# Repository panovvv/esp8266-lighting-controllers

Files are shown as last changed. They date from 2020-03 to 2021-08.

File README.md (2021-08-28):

# ESP8266 Lighting controllers

diyHue-compatible smart lighting controllers from inexpensive easy-to-source components.

* ESP-12 RGBCCT (5 channels) controller

    * Prototype
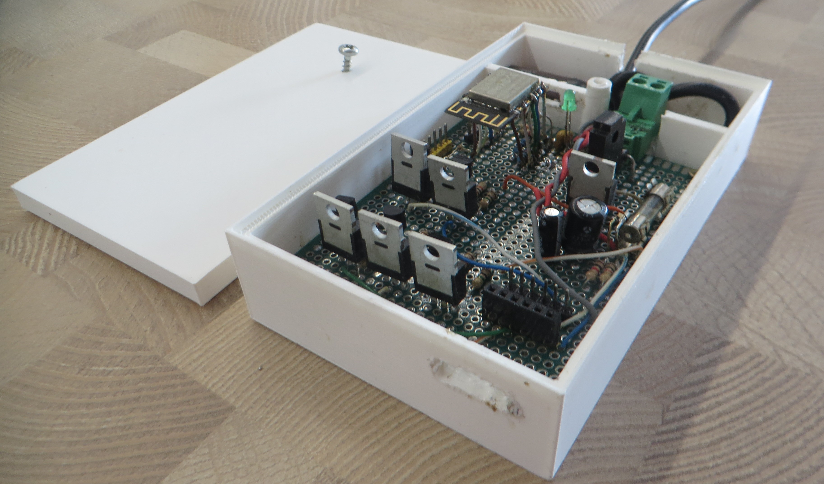
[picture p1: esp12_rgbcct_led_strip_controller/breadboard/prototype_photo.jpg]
      
    * PCB render
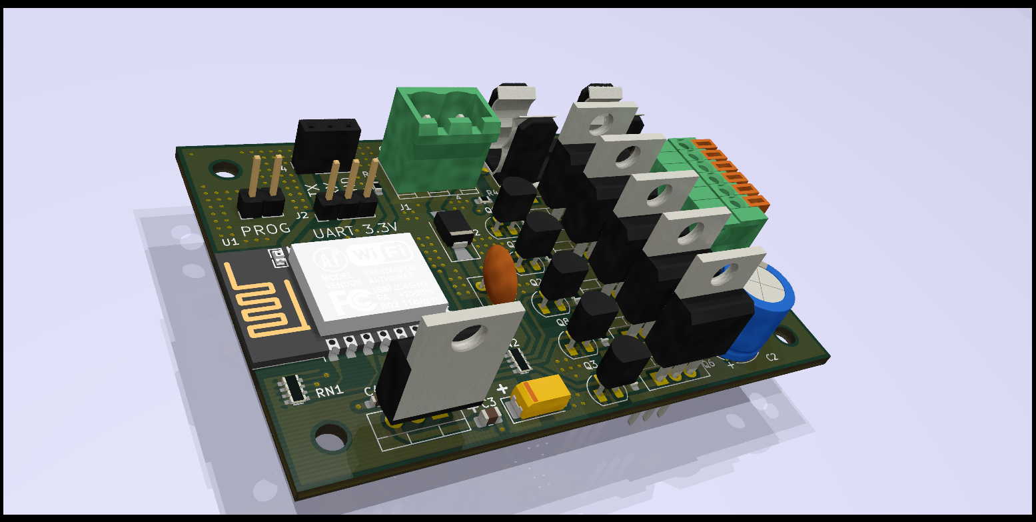
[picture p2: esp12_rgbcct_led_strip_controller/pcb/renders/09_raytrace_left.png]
      
    * PCB
      
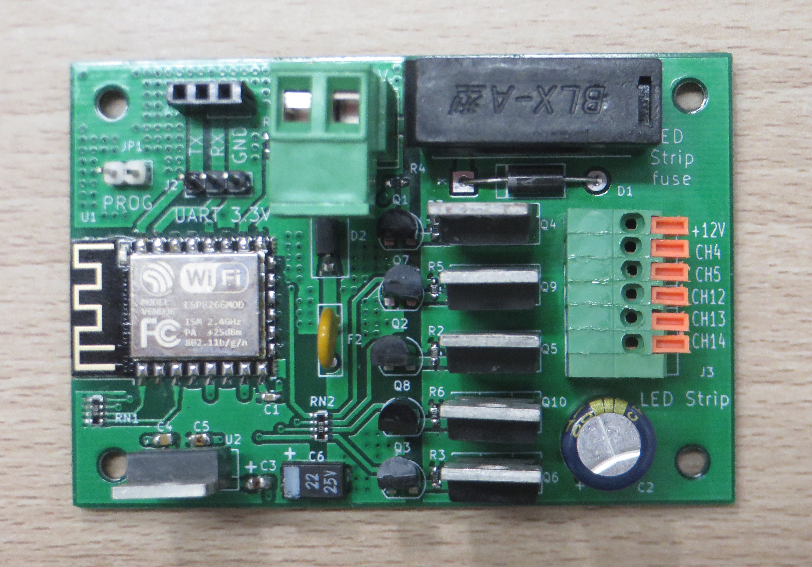
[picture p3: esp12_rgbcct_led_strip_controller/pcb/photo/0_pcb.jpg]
      
    * Regular enclosure
      
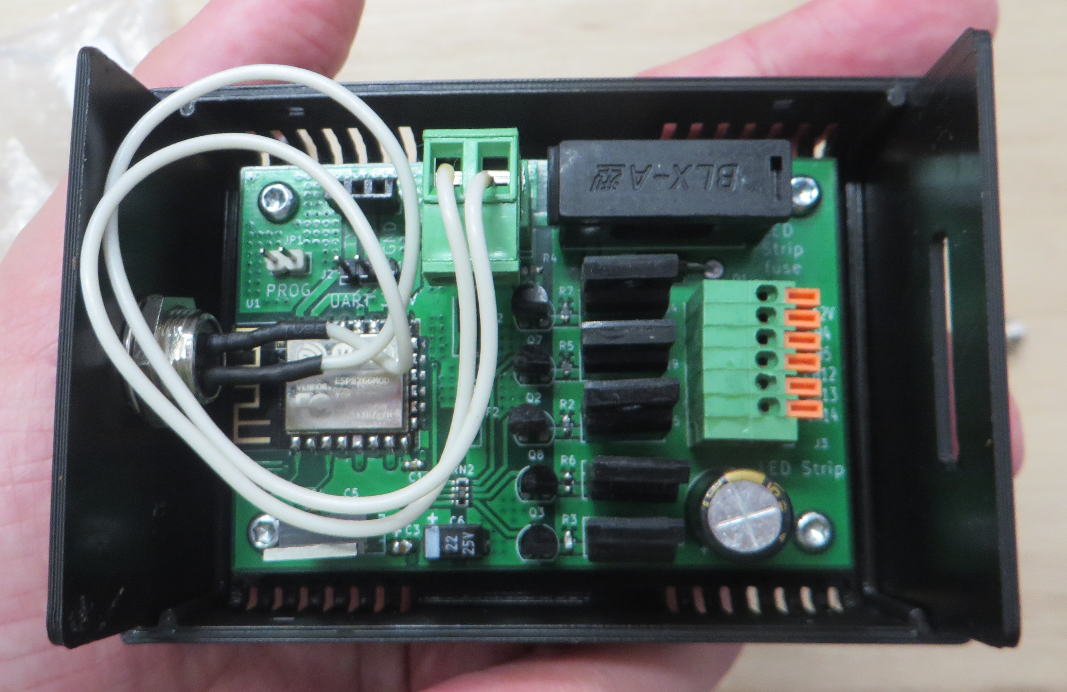
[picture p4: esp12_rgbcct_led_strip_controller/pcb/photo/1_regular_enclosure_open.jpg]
      
      
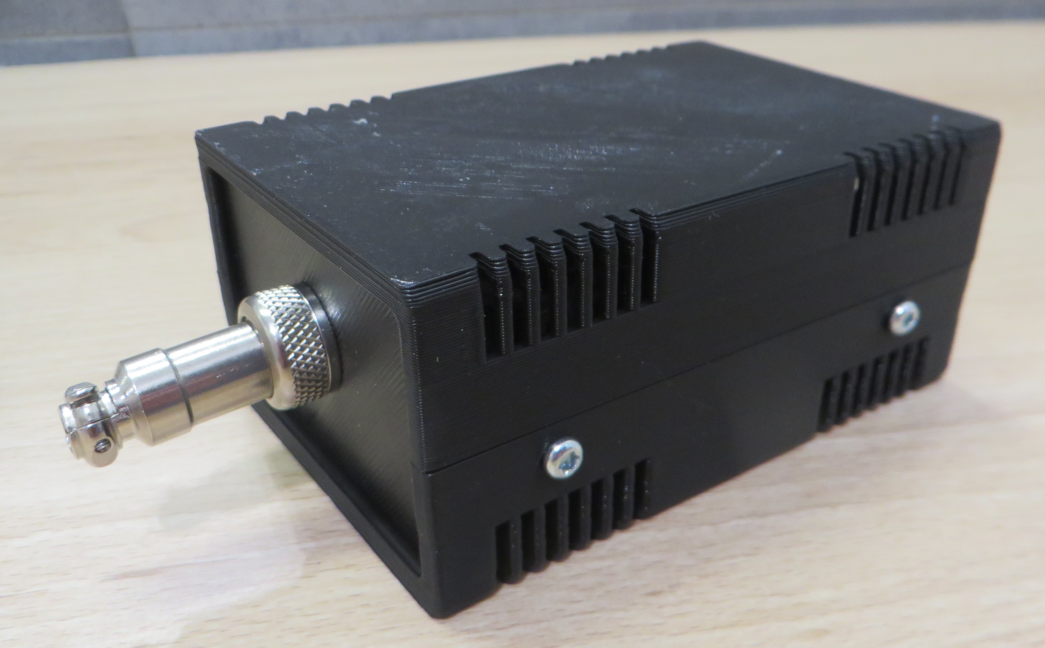
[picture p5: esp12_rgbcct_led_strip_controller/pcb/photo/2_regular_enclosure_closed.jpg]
      
      
    * Waterproof enclosure
      
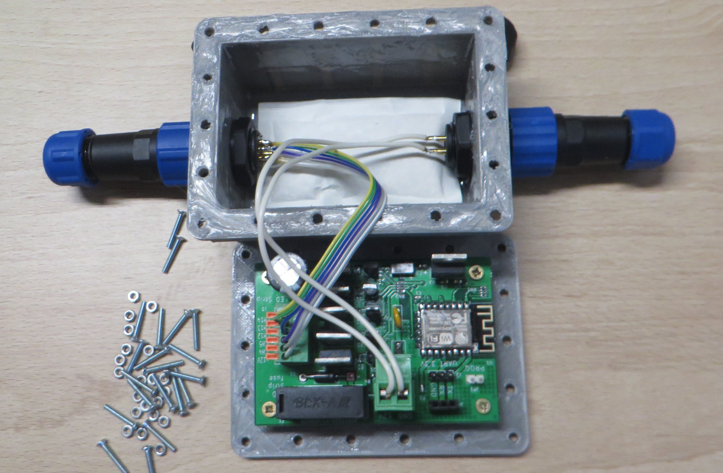
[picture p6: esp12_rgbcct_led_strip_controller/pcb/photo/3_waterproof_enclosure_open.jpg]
      
      
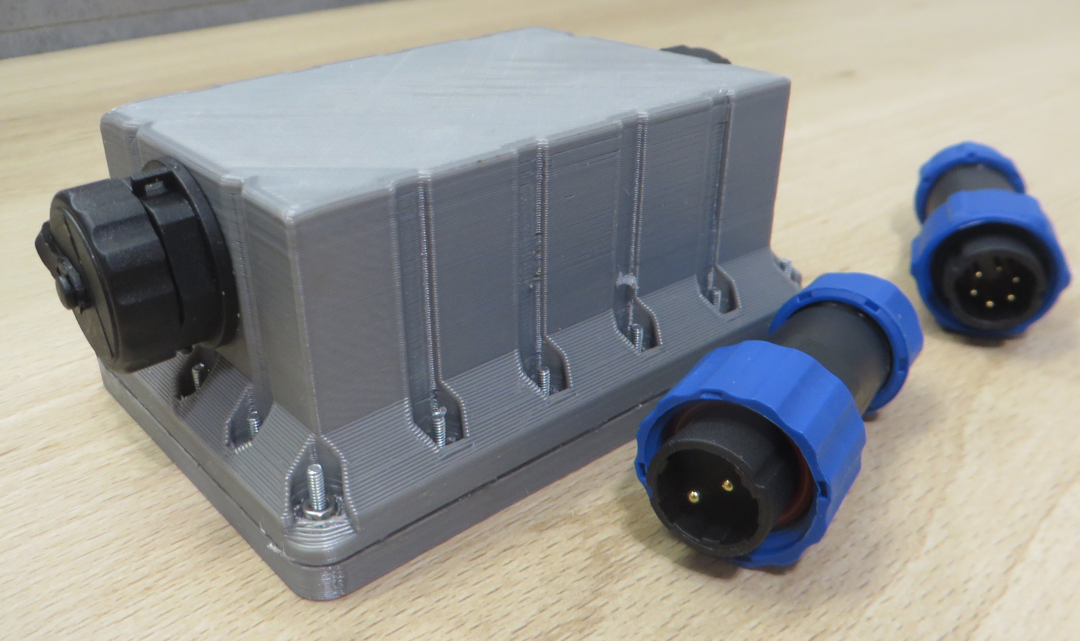
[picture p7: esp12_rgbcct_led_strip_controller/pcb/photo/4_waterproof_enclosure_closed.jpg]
      

* ESP-01 Neopixel (WS2812) controller

    * Schematic
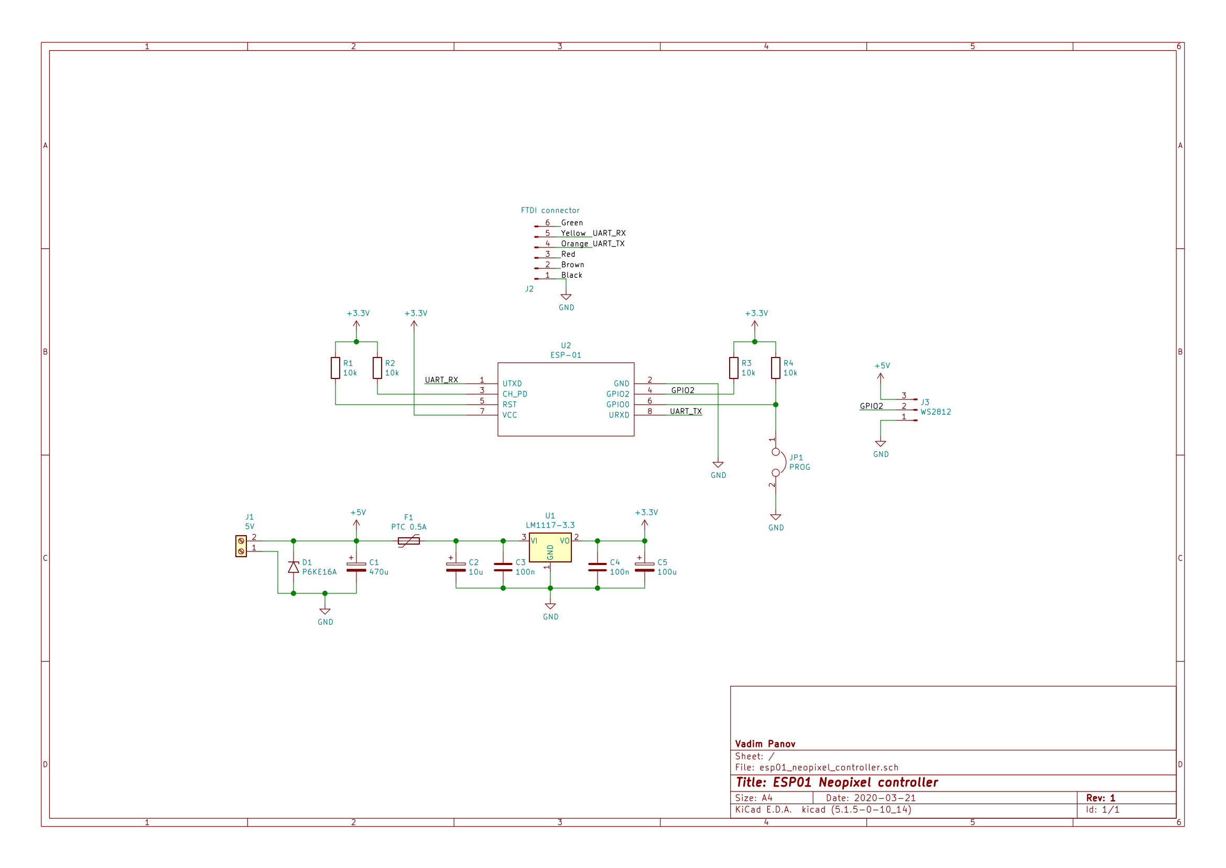
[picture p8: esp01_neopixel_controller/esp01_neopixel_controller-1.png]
      
    * Prototype
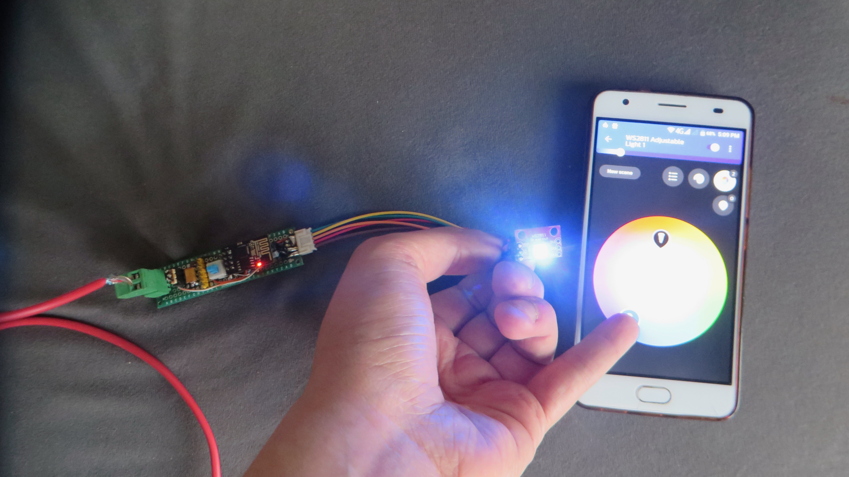
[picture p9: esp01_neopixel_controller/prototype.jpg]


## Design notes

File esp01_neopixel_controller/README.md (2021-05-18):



This schematic uses the ESP-01 symbol from this library:

https://github.com/jdunmire/kicad-ESP8266

Clone this library and point KiCAD to ESP8266.lib 
if you want to customize this schematic.

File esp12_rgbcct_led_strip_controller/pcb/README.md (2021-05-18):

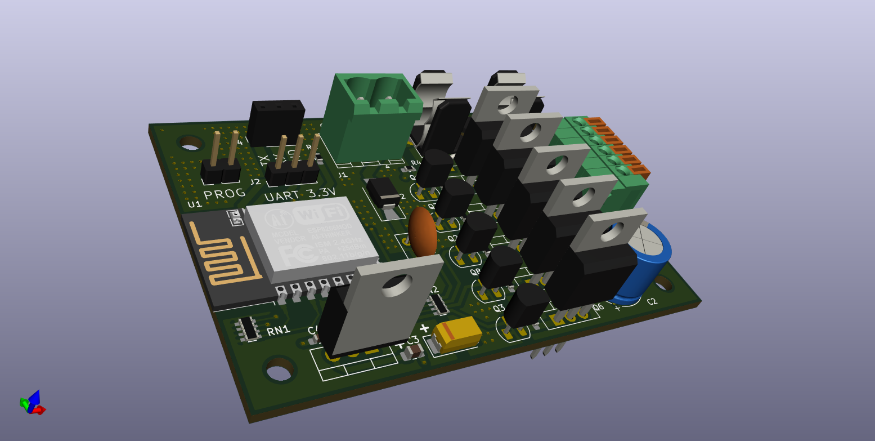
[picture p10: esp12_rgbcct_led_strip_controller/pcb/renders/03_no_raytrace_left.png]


# Files and folders:

* `esp-12_led_strip_controller.***, fp-lib-table` - KiCAD schematics and PCB files.
* `schematic.pdf` - full schematic sheet rendered in PDF.
* `bom.csv` - Bill of Materials, Tab-separated.
* `paper_footprint_test.pdf` - this is my usual practice when designing and ordering PCBs:
before even designing the board layout, I plot the empty board with all footprints in it to PDF
(1:1 scale), print it on a sheet of paper and do a "test fit" for every component. This helps 
to find footprint inconsistencies early on.
* `enclosure/` - OpenSCAD script + STL files. [Source](https://github.com/jbebel/Ultimate-Box-Maker)
* `enclosure_waterproof/` - waterproof enclosure (think bathrooms), designed in FreeCAD 0.18 . 
* `gerber/` - Generated according to
[this document](https://support.jlcpcb.com/article/102-kicad-515---generating-gerber-and-drill-files).
To order the PCB made, just zip up all files in `gerber/` folder and send to fab.
* `renders/` - 3D renders and STL of the board with all components populated.

# Dependencies

* _KF141V-6P_P2.54mm_ footprint from [Connector_KEFA_Homemade](https://github.com/panovvv/homemade-kicad-libraries) 

# BOM

| Designator | Package | Quantity | Designation |
|---|---|---|---|
| R1 - R7 | 0603 (1608 metric) | 7 | 10k resistor. |
| U2 | TO-220 3 pin | 1 | LM1117-3.3 voltage regulator (3.3V) |
| C1, C4, C5 | 0603 (1608 metric) | 3 | 100n capacitor. |
| J3 | KF141V-6P, 2.54mm spacing | 1 | LED Strip connector – spring cage type. |
| C2 | Radial polarized capacitor, D=10.0mm, P=5.00mm/7.50mm | 1 | 1000u capacitor. |
| C3 | 0805 (2012 metric) | 1 | 10u capacitor. |
| C6 | EIA-6032-28 / Kemet-C, pad size: 2.25x2.35mm | 1 | 100u tantalum capacitor (or any other capacitor that fits the footprint) |
| D1 | DO-15 | 1 | P6KE16A - TVS diode 16V. |
| D2 | SMA or SMB (Universal) | 1 | Any surface mount diode in SMA or SMB package. |
| F1 | Cylindric fuse holder - 5x20mm | 1 | LED strip fuse holder. Fuse current = total current consumption of your strip + some headroom. |
| F2 | Disc capacitor, D=8.0mm, W=2.5mm, P=5.00mm | 1 | PTC fuse, 0.5A. |
| Q1, Q2, Q3, Q7, Q8  | TO-92 | 5 | NPN transistor, EBC(123) configuration (e,g, 2N2222) |
| Q4, Q5, Q6, Q9, Q10 | TO-220 3 pin. | 5 | N type MOSFET, GDS(123) configuration (e,g, IRF3205) |
| RN1, RN2 | Resistor array, convex, 4x0603 | 2 | 10k resistor network. |
| U1 | ESP-12 | 1 | ESP-12E or ESP-12F. |
| J1 | PhoenixContact MSTBVA 2,5 2-G-5,08, 1x02, 5.08mm spacing. | 1 | 12V input. Can be replaced with any similar connector. |
| JP1 | Pin header, 1x02, 2.54mm spacing. | 1 | PROG jumper. |
| J2 | Pin header, 1x03, 2.54mm spacing. | 1 | UART male connector. |
| J4 | Pin socket, 1x02, 2.54mm spacing. | 1 | UART female connector. |

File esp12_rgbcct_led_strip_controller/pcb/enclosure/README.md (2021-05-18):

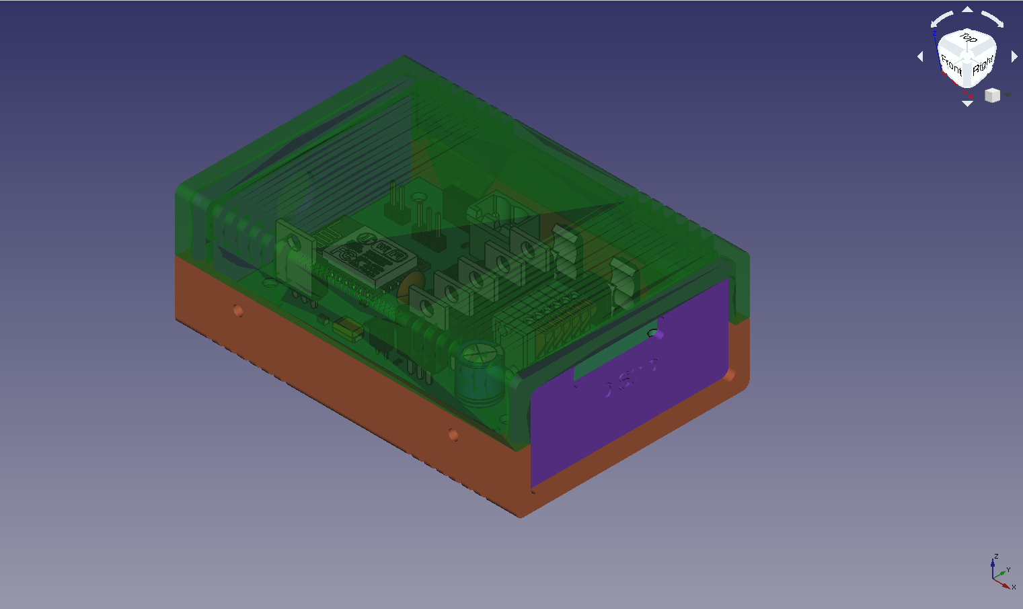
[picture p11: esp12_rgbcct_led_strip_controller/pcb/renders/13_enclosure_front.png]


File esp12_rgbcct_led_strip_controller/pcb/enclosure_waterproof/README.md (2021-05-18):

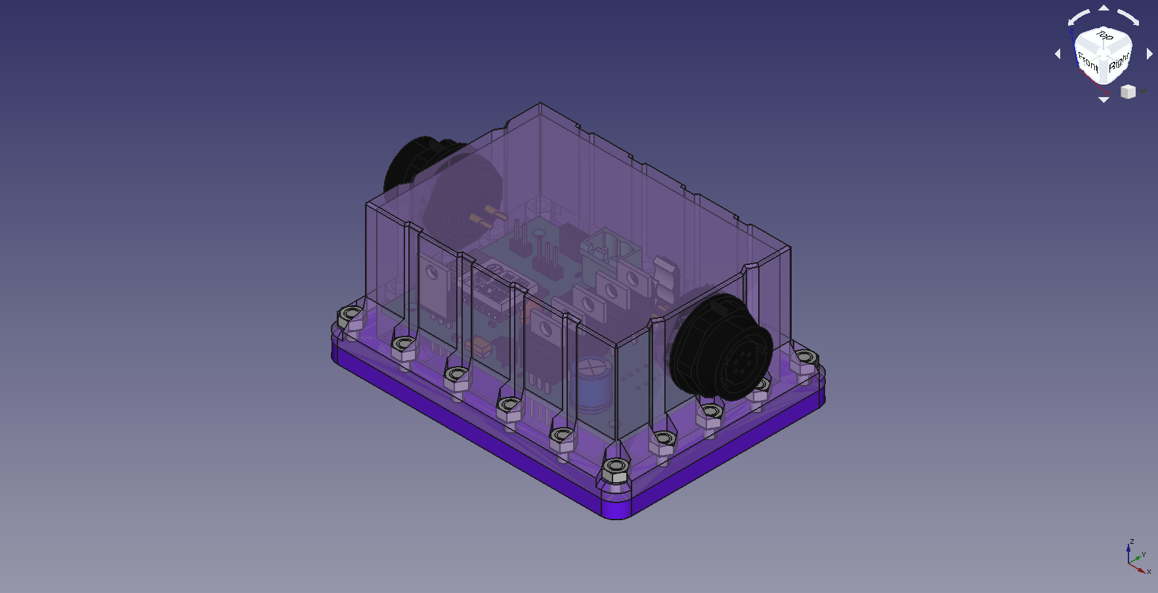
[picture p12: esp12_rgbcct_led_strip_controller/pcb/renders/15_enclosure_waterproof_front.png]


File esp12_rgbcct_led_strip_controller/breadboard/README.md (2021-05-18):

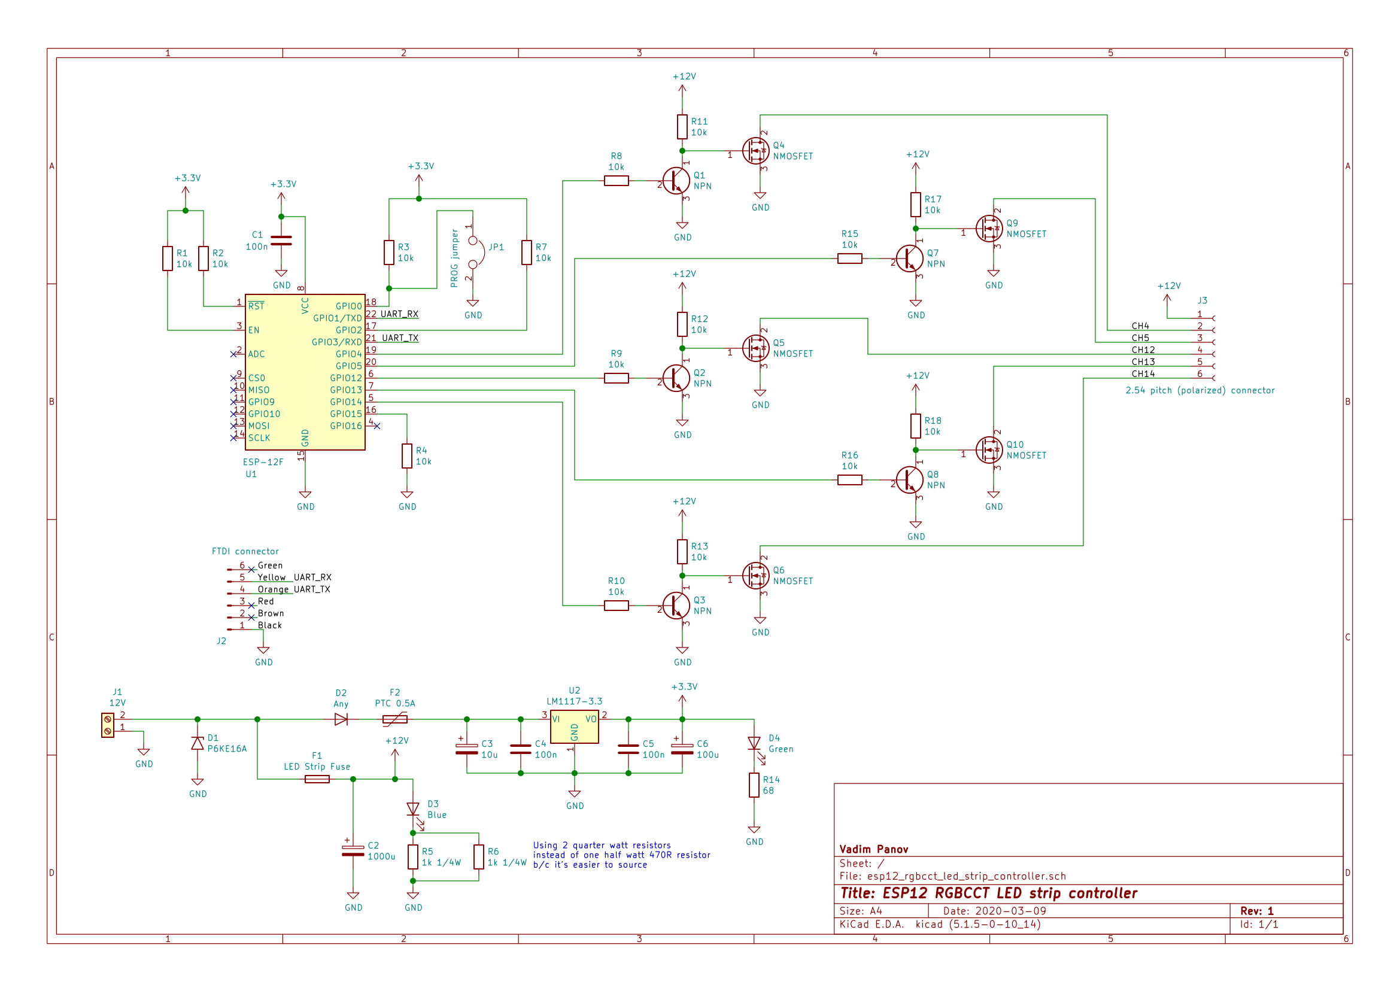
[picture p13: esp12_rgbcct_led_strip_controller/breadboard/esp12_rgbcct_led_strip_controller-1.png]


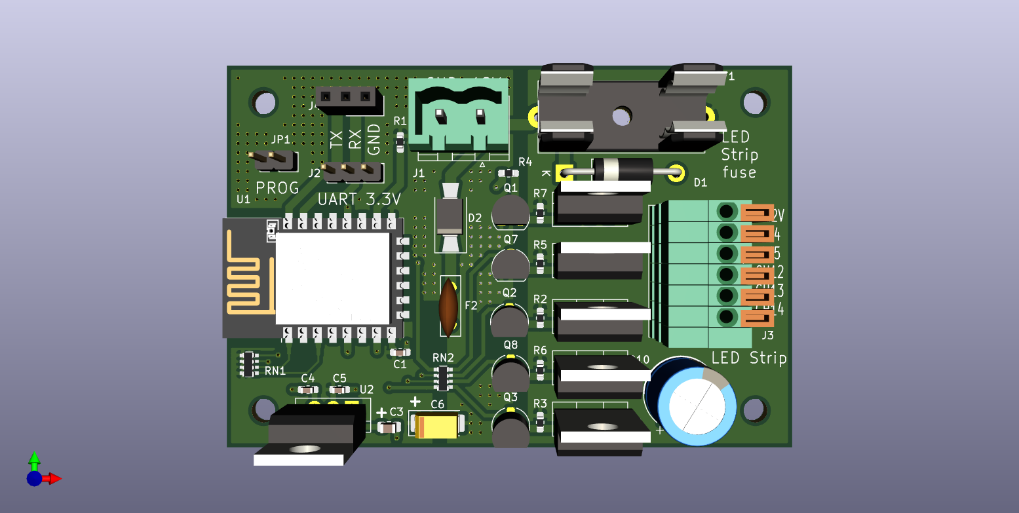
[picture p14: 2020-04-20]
esp12_rgbcct_led_strip_controller/pcb/renders/01_no_raytrace_front.png

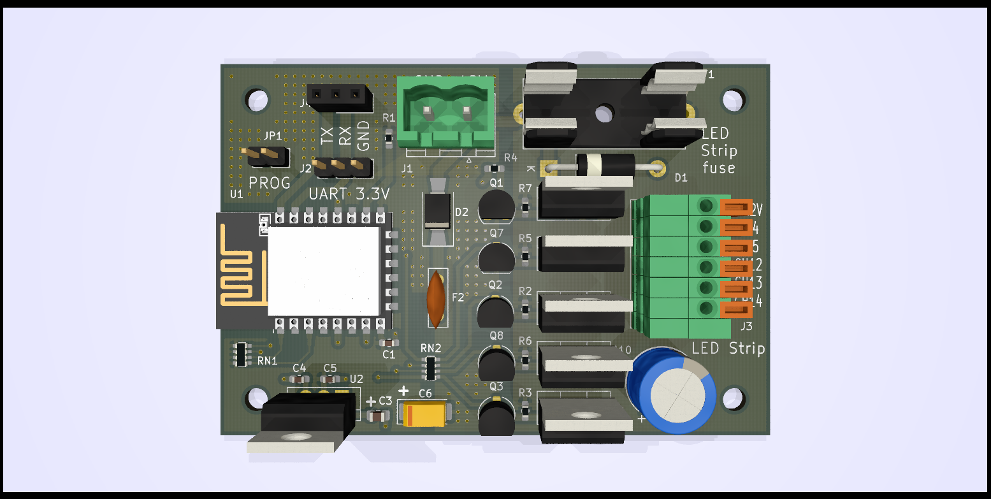
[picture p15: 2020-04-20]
esp12_rgbcct_led_strip_controller/pcb/renders/07_raytrace_front.png

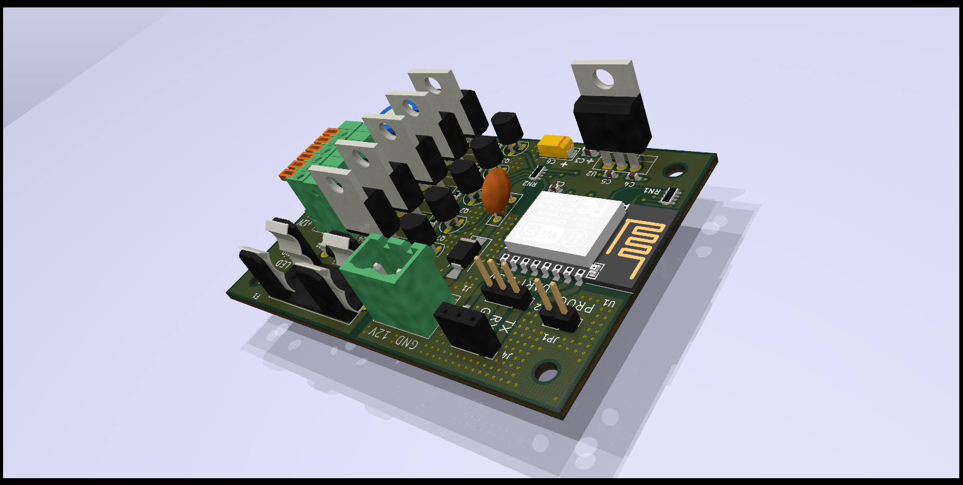
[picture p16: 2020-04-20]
esp12_rgbcct_led_strip_controller/pcb/renders/11_raytrace_left_180deg.png

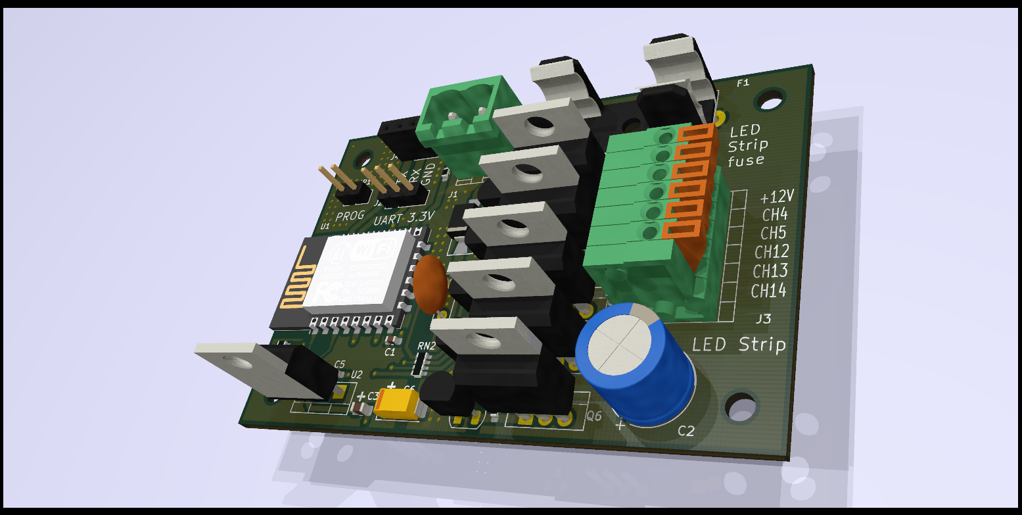
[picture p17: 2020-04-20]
esp12_rgbcct_led_strip_controller/pcb/renders/10_raytrace_right.png

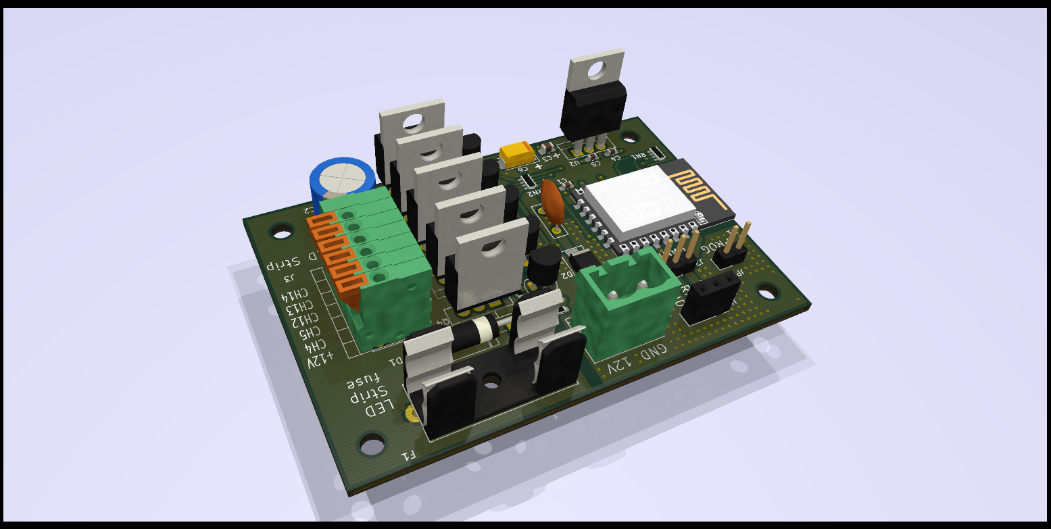
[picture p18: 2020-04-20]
esp12_rgbcct_led_strip_controller/pcb/renders/12_raytrace_right_180deg.png

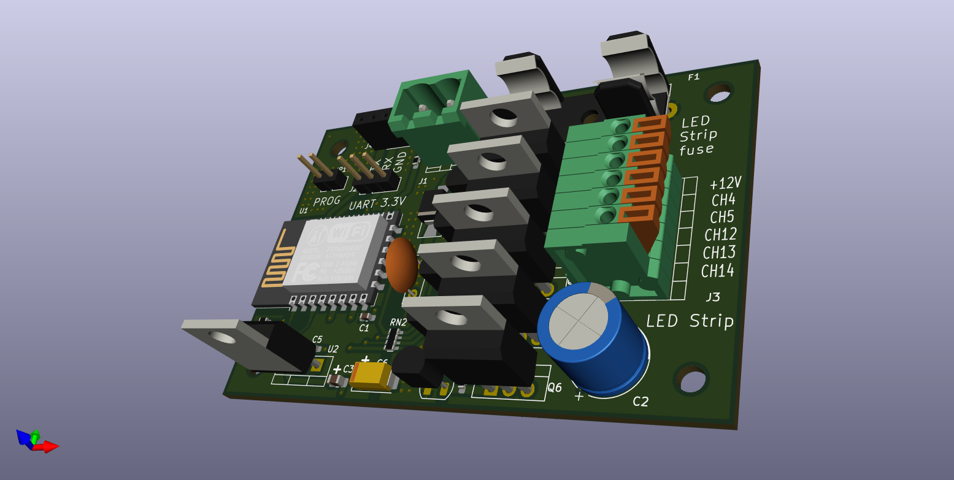
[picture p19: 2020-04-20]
esp12_rgbcct_led_strip_controller/pcb/renders/04_no_raytrace_right.png

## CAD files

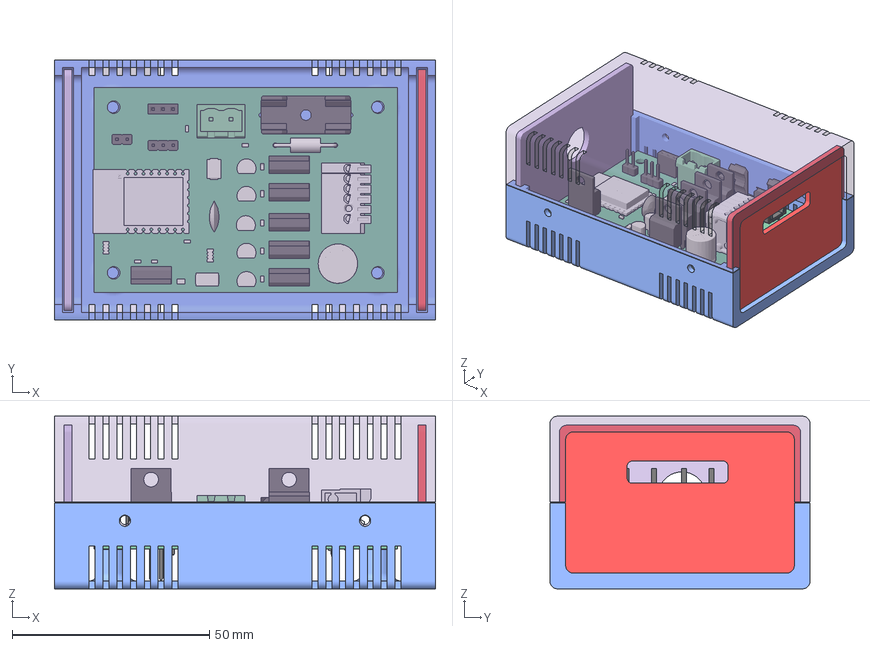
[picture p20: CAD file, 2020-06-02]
esp12_rgbcct_led_strip_controller/pcb/enclosure/full_assembly.FCStd
96.6 x 66.0 x 43.8 mm
Pcb_5b54
R6_R_0603_1608Metric_5E9C2952
R5_R_0603_1608Metric_5E9C2A8A
R3_R_0603_1608Metric_5E9C2982
R2_R_0603_1608Metric_5E9C29B2
U2_TO-220-3_Vertical_5E9B5751
C5_C_0603_1608Metric_5E9B5718
C4_C_0603_1608Metric_5E9B56E5
J3_KF141V-6P_P2.54mm_5E9C2657
C1_C_0603_1608Metric_5E91E38A
C2_CP_Radial_D100mm_P500mm_P750mm_5E9CC6F6
C3_C_0805_2012Metric_5E91E46E
C6_CP_EIA_6032_28_Kemet_C_5E9C8505
D1_D_DO-15_P15.24mm_Horizontal_5E9B9CF2
D2_D_SMB_5E9B6E28
F1_A_Schurter_0031_8201_5E9C40DC
F2_C_Disc_D80mm_W25mm_P500mm_5E9CBA76
Q1_TO-92_Narrow_5E9C2AEB
Q2_TO-92_Narrow_5E9C2B1E
Q3_TO-92_Narrow_5E9C0DBD
Q4_TO-220-3_Vertical_5E9C0E43
Q5_TO-220-3_Vertical_5E9C0CE1
Q6_TO-220-3_Vertical_5E9B9F12
Q7_TO-92_Narrow_5E9C2A58
Q8_TO-92_Narrow_5E9C2A25
Q9_TO-220-3_Vertical_5E9C0E8E
Q10_TO-220-3_Vertical_5E9C0B8E
R1_R_0603_1608Metric_5E92F775
R7_R_0603_1608Metric_5E9C2B50
RN1_R_Array_Convex_4x0603_5E9C9216
RN2_R_Array_Convex_4x0603_5E9C29E8
U1_ESP-12-E-better_5E9C08FA
J1_MSTBVA_01x02_G_5_08mm_5E9B6F19
JP1_PinHeader_1x02_P254mm_Vertical_5E9244EE
R4_R_0603_1608Metric_5E9C2ABA
J2_PinHeader_1x03_P254mm_Vertical_5E94568C
J4_PinSocket_1x03_P254mm_Vertical_5E945586
bottom
top
back
front

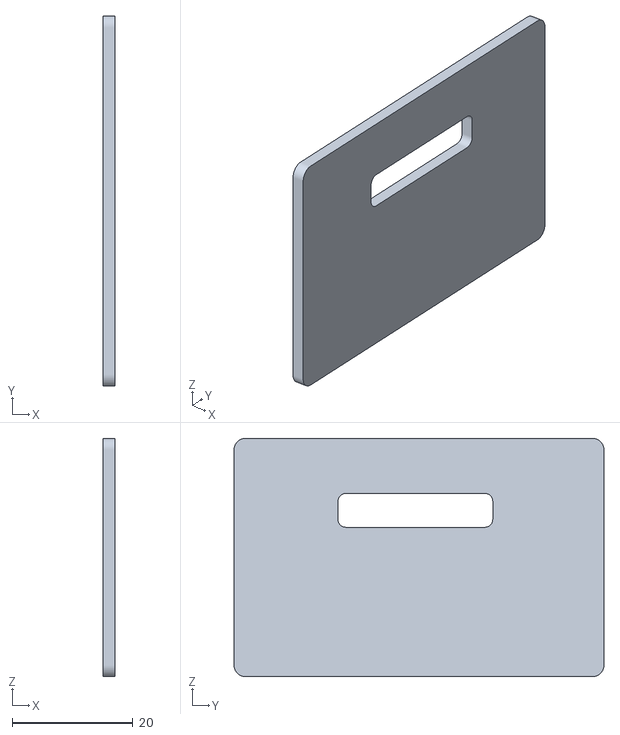
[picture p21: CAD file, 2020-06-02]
esp12_rgbcct_led_strip_controller/pcb/enclosure/front.stl
2.00 x 61.2 x 39.4

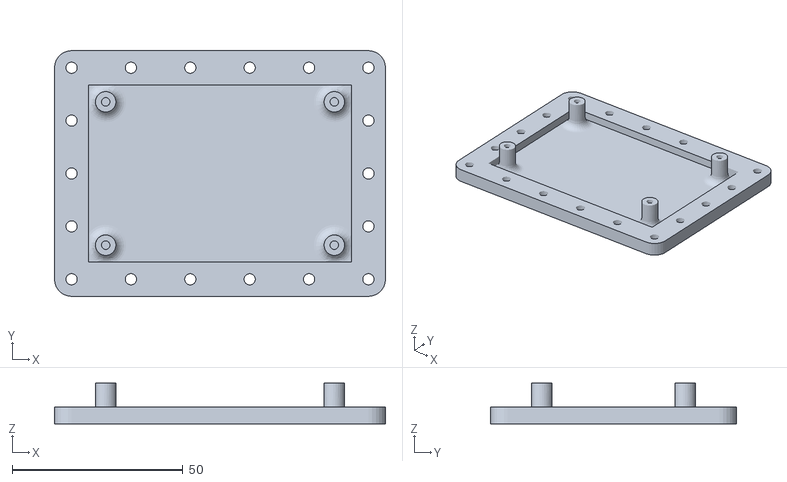
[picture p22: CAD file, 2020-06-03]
esp12_rgbcct_led_strip_controller/pcb/enclosure_waterproof/enclosure_bottom.stl
97.0 x 72.0 x 12.0

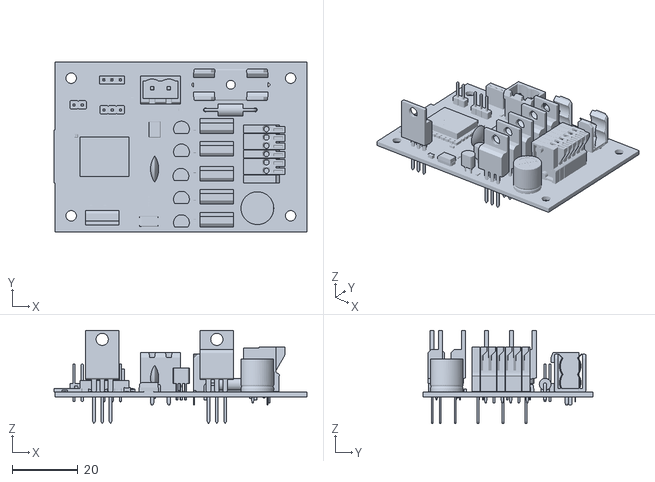
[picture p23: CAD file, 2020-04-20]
esp12_rgbcct_led_strip_controller/pcb/renders/esp-12_led_strip_controller.stl
77.2 x 52.0 x 28.5

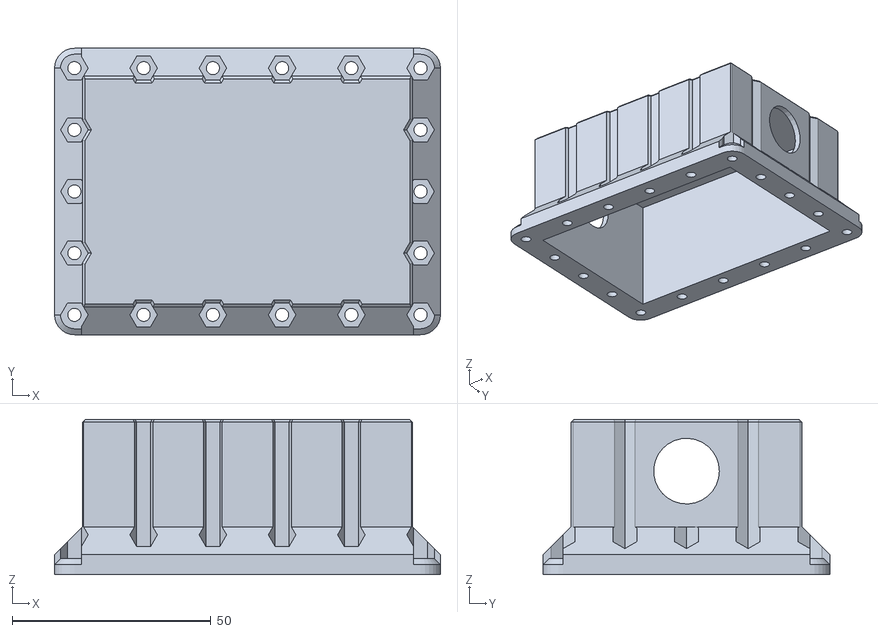
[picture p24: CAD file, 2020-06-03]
esp12_rgbcct_led_strip_controller/pcb/enclosure_waterproof/enclosure_top.stl
97.0 x 72.0 x 39.0

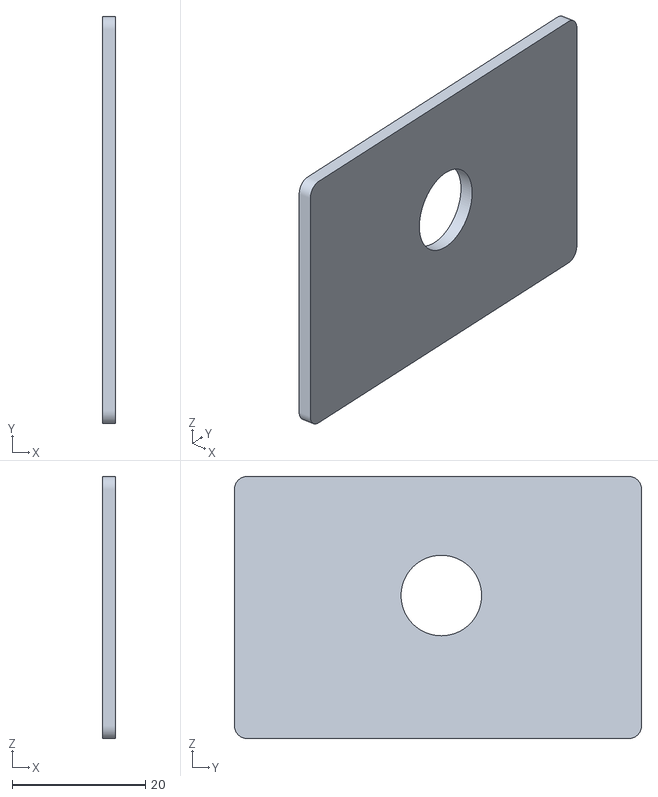
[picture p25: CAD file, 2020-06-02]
esp12_rgbcct_led_strip_controller/pcb/enclosure/back.stl
2.00 x 61.2 x 39.4

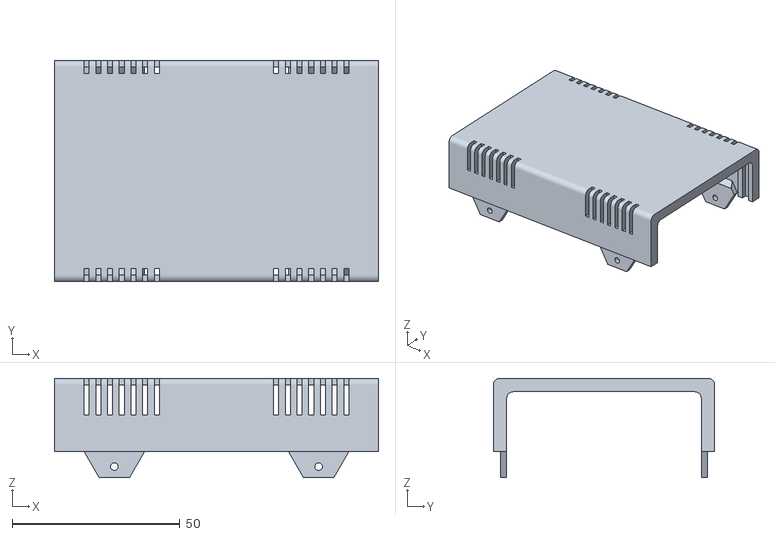
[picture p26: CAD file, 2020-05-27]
esp12_rgbcct_led_strip_controller/pcb/enclosure/top.stl
96.6 x 66.0 x 29.6

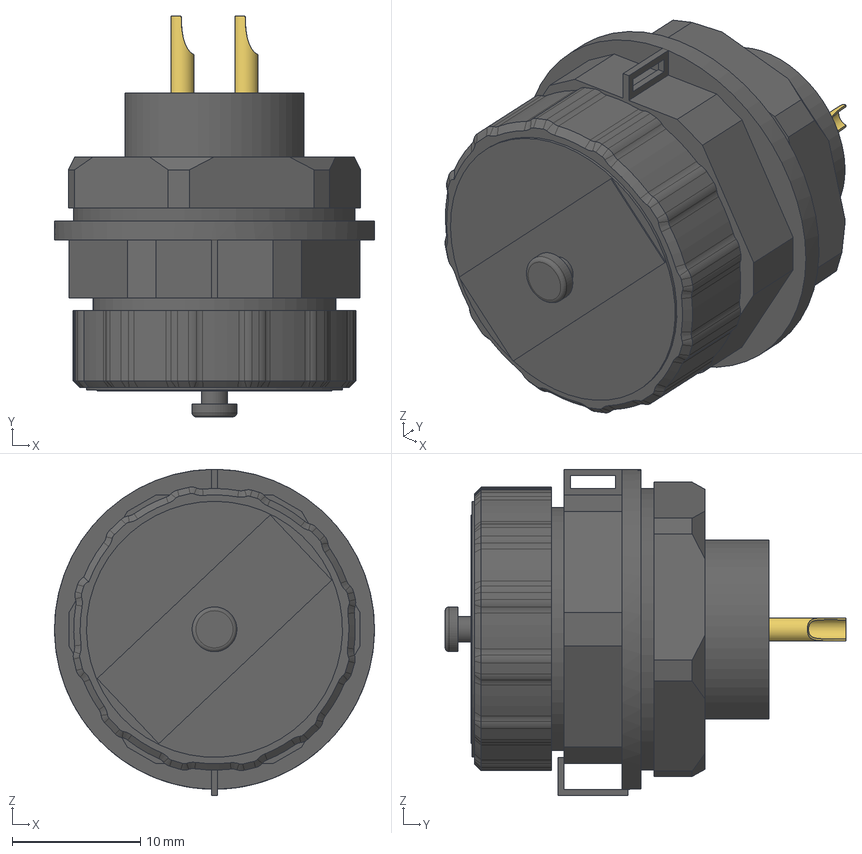
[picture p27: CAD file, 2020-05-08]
esp12_rgbcct_led_strip_controller/pcb/enclosure_waterproof/SP16-2P, female, back nut type, with cap.stp
25.0 x 31.3 x 25.5 mm
cap
rubber_washer
nut
nut_1
center_2p_female_body
pin x 2

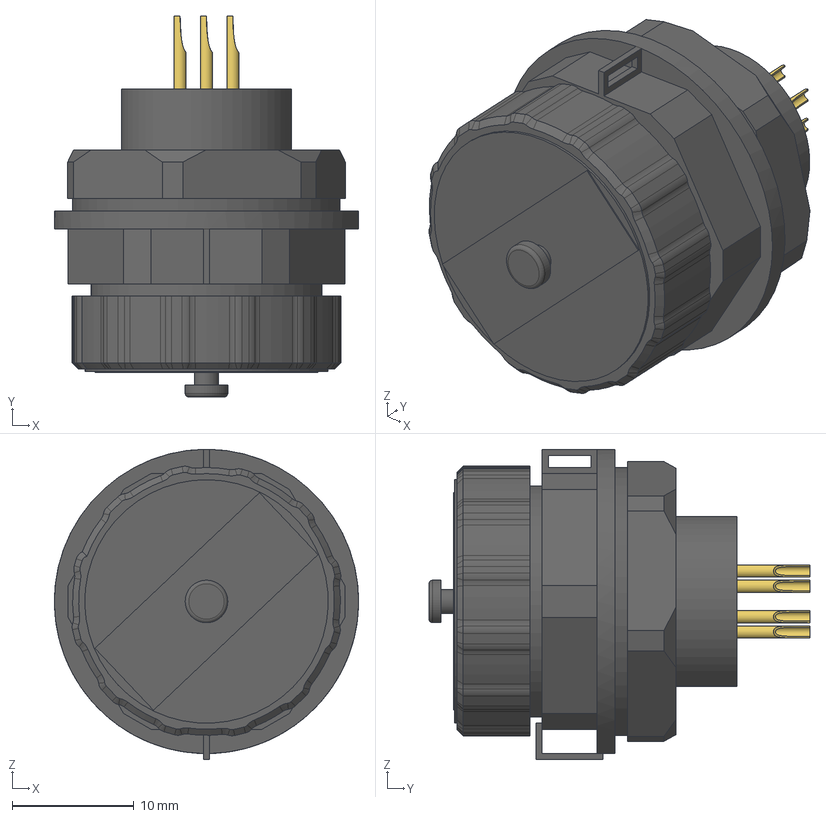
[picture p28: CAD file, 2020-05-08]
esp12_rgbcct_led_strip_controller/pcb/enclosure_waterproof/SP16-6P, female, back nut type, with cap.stp
25.0 x 31.3 x 25.5 mm
cap
rubber_washer
nut
nut_1
center_2p_female_body
pin x 6

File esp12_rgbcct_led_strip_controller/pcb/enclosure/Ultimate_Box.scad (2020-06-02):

/* Box design originally by:
////////////////////////////////////////////////////////////////////
              -    FB Aka Heartman/Hearty 2016     -
              -   http://heartygfx.blogspot.com    -
              -       OpenScad Parametric Box      -
              -         CC BY-NC 3.0 License       -
////////////////////////////////////////////////////////////////////

Improved by jbebel:
http://github.com/jbebel/Ultimate-Box-Maker

To create a box, start by modifying the numerical parameters in the sections
below. This can be accomplished using a release of OpenSCAD newer than 2015.03.
As of the time of writing, this means that a development snapshot is required.
The Thingiverse Customizer may also potentially work, but at the time of
writing, it was inoperable.

The simplest choice is to hand-edit the .scad file. Feature toggles are
annotated with a comment. The other numerical parameters are measurements in
mm. Everything is parametrized, so if you double all the non-feature parameters
you will double the box size in every dimension. Certain parameters are derived
from other parameters. If you wish to override them, you may, but sensible
defaults have been chosen. Notably the design in this revision is particularly
PCB-centric, in that you should start with your PCB size and adjust the margins
around it to determine the box size. If you care more about the box size, you
can set the Length, Width, and Height explicitly, but read the comments around
them.

Once your box is sized appropriately, you can use the Panel modules to design
the holes and text for the front and back panels. Helper variables are provided
to assist you in positioning these holes relative to the PCB, if your holes are
for PCB-mounted components.

When you are ready to print, adjust the values in the "STL element to export"
section, and export each part one at a time.

Experimental options are provided for a screwless design, but these are
untested. In particular, the box fixation tabs may need thicknesses adjusted
in order to have the appropriate flexibility.
*/

// preview[view:north east, tilt:top diagonal]
//----------------------- Box parameters ---------------------------

/* [Box options] */
// - Wall thickness
Thick = 2;
// - Panel thickness
PanelThick = 2;
// - Font Thickness
FontThick = 0.5;
// - Filet Radius
Filet = 2;
// - 0 for beveled, 1 for rounded
Round = 1; // [0:No, 1:Yes]
// - Printer margin around interior cutouts
CutoutMargin = 0.3;
// - Margin between mating parts
PartMargin = 0.1;
// - PCB feet? (x4)
PCBFeet = 1; // [0:No, 1:Yes]
// - Decorations?
Decorations = 1; // [0:No, 1:Yes]
// - Decorations to ventilation holes
Vent = 1; // [0:No, 1:Yes]
// - Decoration-Holes width (in mm)
Vent_width = 1.5;
// - Tolerance (Panel/rails gap on one edge)
PanelThickGap = CutoutMargin + PartMargin;
PanelVerticalGap = PartMargin;
PanelHorizontalGap = CutoutMargin + PartMargin;


/* [Box Fixation Tabs] */
// - Side screw hole (or snap) diameter
ScrewHole = 2.2606;
// - Screw thread major diameter for outer shell
BoxHole = 2.8448;
// Thickness of fixation tabs
TabThick = 2;
// Back left tab
BLTab = 1; // [0:Bottom, 1:Top]
// Back right tab
BRTab = 1; // [0:Bottom, 1:Top]
// Front left tab
FLTab = 1; // [0:Bottom, 1:Top]
// Front right tab
FRTab = 1; // [0:Bottom, 1:Top]
// EXPERIMENTAL: Snap tabs
SnapTabs = 0; // [0:Screws, 1:Snaps]


/* [PCB options] */
// - PCB Length
PCBLength = 80;
// - PCB Width
PCBWidth = 144;
// - PCB Thickness
PCBThick = 1.6;
// You likely need to maintain |TabThick| margin on the left and right for tabs
// and whatnot.
// - Margin between front panel and PCB
FrontEdgeMargin = 70;
// - Margin between back panel and PCB
BackEdgeMargin = 0;
// - Margin between left wall and PCB
LeftEdgeMargin = 11;
// - Margin between right wall and PCB
RightEdgeMargin = 11;
// - Margin between top of PCB and box top.
TopMargin = 84;


/* [PCB_Feet] */
// - Foot height above box interior
FootHeight = 8;
// - Foot diameter
FootDia = 8;
// - Hole diameter, or peg for screwless design
FootHole = 2.2606; // tap size for #4 coarse-thread
// - EXPERIMENTAL Screwless design
Screwless = 0; // [0:Screws, 1:Screwless]
FootFilet = FootHeight/4;

// Foot centers are specified as distance from PCB back-left corner.
// X is along the "length" axis, and Y is along the "width" axis.
// - Foot 1 distance from back PCB edge
Foot1X = 5;
// - Foot 1 distance from left PCB edge
Foot1Y = 5;
// - Foot 2 distance from back PCB edge
Foot2X = 5;
// - Foot 2 distance from right PCB edge
Foot2YFromEdge = 5;
Foot2Y = PCBWidth - Foot2YFromEdge;
// - Foot 3 distance from front PCB edge
Foot3XFromEdge = 5;
Foot3X = PCBLength - Foot3XFromEdge;
// - Foot 3 distance from left PCB edge
Foot3Y = 5;
// - Foot 4 distance from front PCB edge
Foot4XFromEdge = 5;
Foot4X = PCBLength - Foot4XFromEdge;
// - Foot 4 distance from right PCB edge
Foot4YFromEdge = 5;
Foot4Y = PCBWidth - Foot4YFromEdge;


/* [STL element to export] */
// - Top shell
TShell = 0; // [0:No, 1:Yes]
// - Bottom shell
BShell = 1; // [0:No, 1:Yes]
// - Front panel
FPanL = 1; // [0:No, 1:Yes]
// - Back panel
BPanL = 1; // [0:No, 1:Yes]
// - Panel holes and text
PanelFeatures = 0; // [0:No, 1:Yes]


/* [Hidden] */
// - Shell color
Couleur1 = "Orange";
// - Panel color
Couleur2 = "OrangeRed";
// - Text color
TextColor = "White";
// - making decorations thicker if it is a vent to make sure they go through
// shell
// Add a small number to Thick in case Filet is 0.
Dec_Thick = Vent ? Thick*1.001 + Filet : Thick/2;
// Separate vents with a square pillar by default.
Dec_Spacing = Thick + Vent_width;
// X offset to center of first vent
Dec_Offset = Thick*2 + PanelThick + PanelThickGap*2 + Dec_Spacing - Vent_width/2;

// Resolution based on Round parameter. Set this first number to something
// smaller to speed up processing. It should always be a multiple of 4.
Resolution = Round ? 100: 4;

/* Calculate box dimensions from PCB. If you want a more box-centric design
   where the outer diameter of the box matters more than the margins around
   the PCB you can set these manually. The PCB will still be placedaccording
   to the left and back margins, and if you want to use the screwless box
   design, you will need to set the TopMargin to
   (Height - Thick*2 - FootHeight - PCBThick)
*/
Length = PCBLength + FrontEdgeMargin + BackEdgeMargin + ((Thick + PanelThick + PanelThickGap*2)*2);
Width = PCBWidth + LeftEdgeMargin + RightEdgeMargin + Thick*2;
Height = FootHeight + PCBThick + TopMargin + Thick*2;
echo("Box: ", Length=Length, Width=Width, Height=Height);
// X position inset of mounting holes and tabs
MountInset = Thick*3 + PanelThick + PanelThickGap*2 + ScrewHole*4;

// Calculate panel dimensions from box dimensions.
PanelWidth = Width - Thick*2 - PanelHorizontalGap*2;
PanelHeight = Height - Thick*2 - PanelVerticalGap*2;


/*  Panel Manager

    Use the below 4 modules to produce holes and text on the front and back
    panels. The holes modules should contain instances of SquareHole or
    CylinderHole defined later in this file. The text modules should contain
    instances of LText or CText defined later in this file. It is
    recommended to use variables that you define for your needs to create
    the size and positions of these objects.
*/

// Calculate board-relative positions with respect to the panel, for
// convenience in placing panel elements.
TopOfBoardWRTPanel = FootHeight + PCBThick - PanelVerticalGap;
LeftEdgeOfBoardWRTFPanel = LeftEdgeMargin - PanelHorizontalGap;
LeftEdgeOfBoardWRTBPanel = RightEdgeMargin - PanelHorizontalGap;
// Visible panel edges
PanelBottomEdge = Thick - PanelVerticalGap;
PanelTopEdge = PanelHeight - Thick + PanelVerticalGap;
PanelLeftEdge = Thick - PanelHorizontalGap;
PanelRightEdge = PanelWidth - Thick + PanelHorizontalGap;


// Holes for front panel
module FPanelHoles() {
    // SquareHole(On/Off, Xpos,Ypos,Length,Width,Filet)
    SquareHole(1, (PanelRightEdge-PanelLeftEdge)/2-11.5, 25, 25, 5, 1);
    // SquareHole(1, 40, 20, 15, 10, 1);
    // SquareHole(1, 60, 20, 15, 10, 1);
    // CylinderHole(On/Off, Xpos, Ypos, Diameter)
    // CylinderHole(1, 27, 40, 8);
    // CylinderHole(1, 47, 40, 8);
    // CylinderHole(1, 67, 40, 8);
    // SquareHole(1, 20, 50, 80, 30, 3);
    // CylinderHole(1, 93, 30, 10);
    // SquareHole(1, 120, 20, 30, 60, 3);
}


// Text for front panel
module FPanelText() {
    // LText(On/Off, Xpos, Ypos, "Font", Size, "Text", "HAlign", "VAlign")
    //LText(1, (PanelRightEdge-PanelLeftEdge)/2-12.5, 13, "Arial Black", 4, "LED Strip", HAlign="left");
    // LText(1, 120, 83, "Arial Black", 4, "Level", HAlign="left");
    // LText(1, 20, 11, "Arial Black", 6, "  1     2      3", HAlign="left");
    // CText(On/Off, Xpos, Ypos, "Font", Size, Diameter, Arc(Deg), Starting Angle(Deg),"Text")
    // CText(1, 93, 29, "Arial Black", 4, 10, 180, 0,
    //      ["1", "." , "3", "." , "5", "." , "7", "." , "9", "." , "11"]);
}
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

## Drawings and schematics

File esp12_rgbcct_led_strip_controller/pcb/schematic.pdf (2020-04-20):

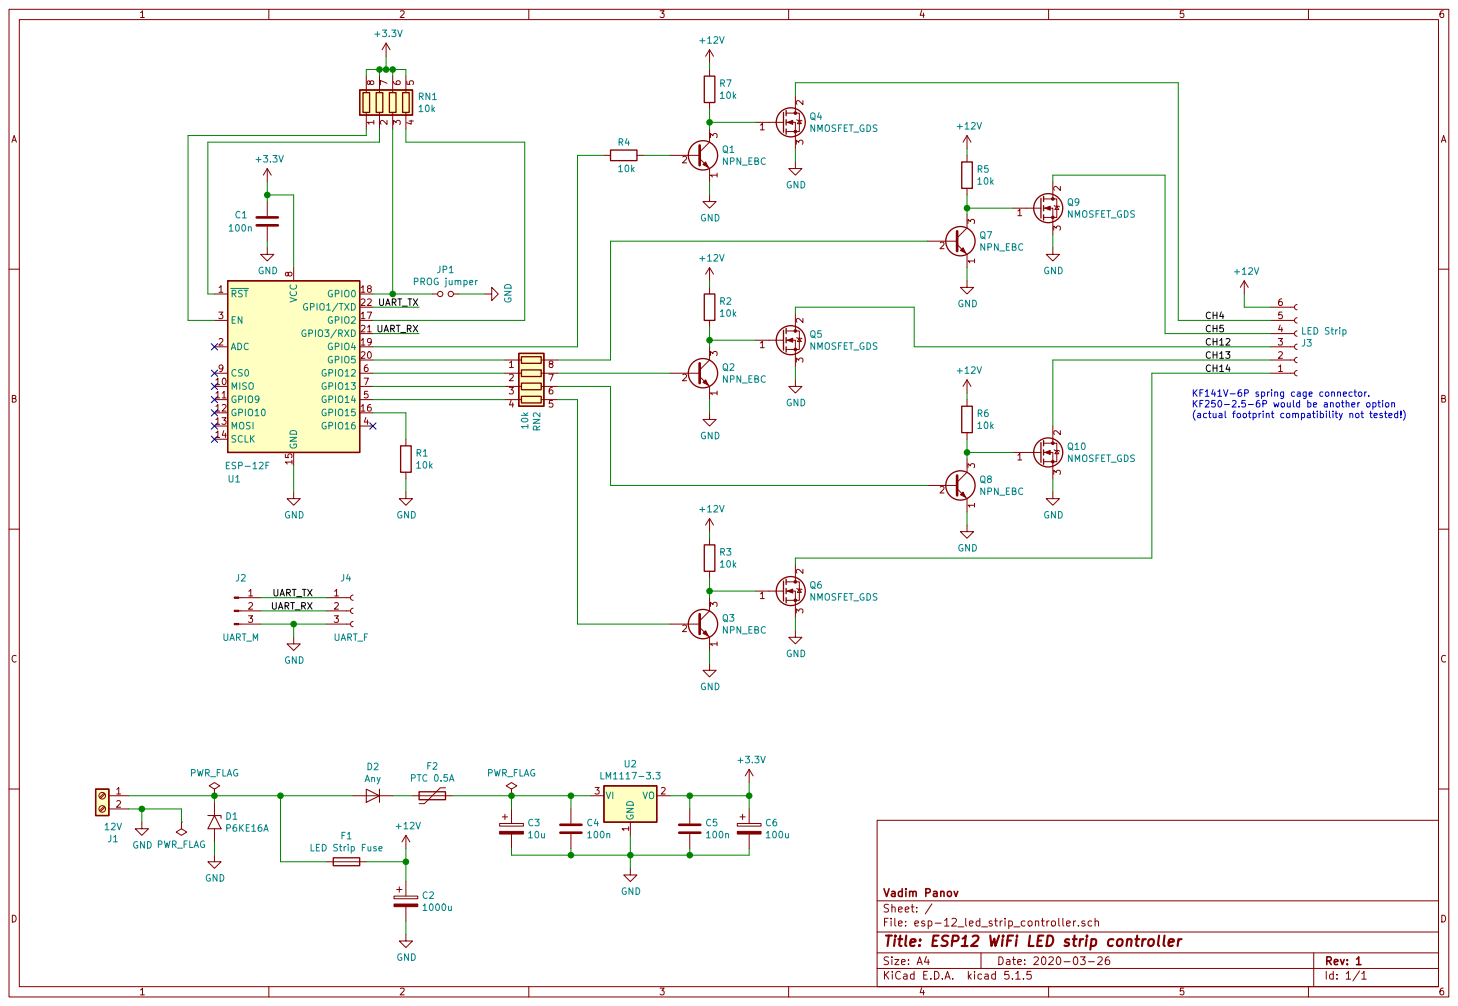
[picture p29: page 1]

KF250-2.5-6P would be another option
(actual footprint compatibility not tested!)

File: esp-12_led_strip_controller.sch Sheet: / Vadim Panov

Id: 1/1 Title: ESP12 WiFi LED strip controller

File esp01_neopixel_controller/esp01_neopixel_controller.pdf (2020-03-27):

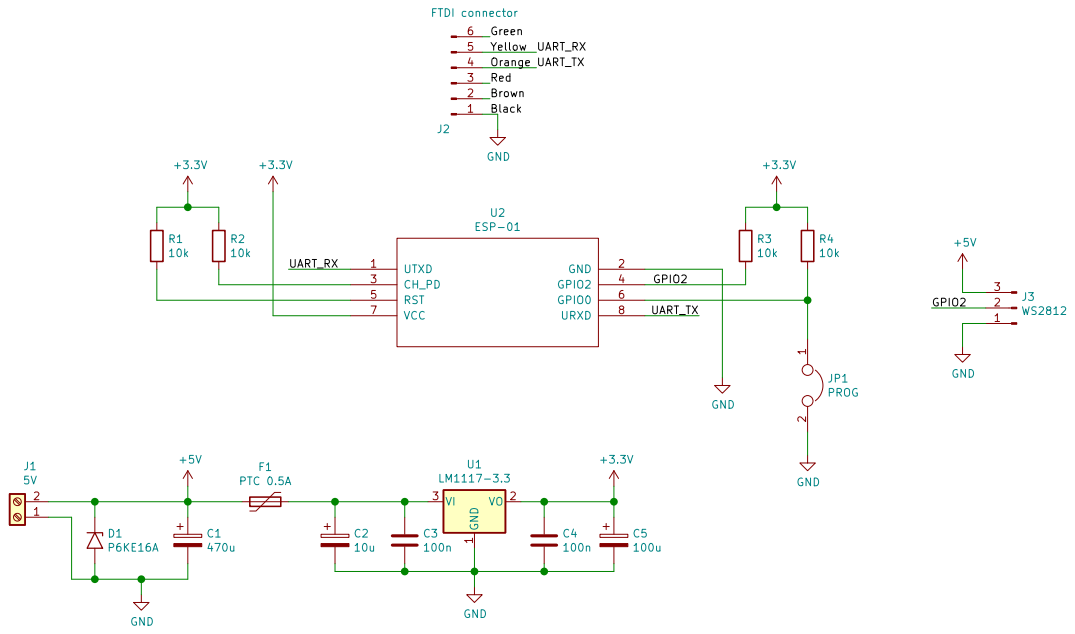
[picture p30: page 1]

File: esp01_neopixel_controller.sch Sheet: / Vadim Panov GND

Id: 1/1 Title: ESP01 Neopixel controller

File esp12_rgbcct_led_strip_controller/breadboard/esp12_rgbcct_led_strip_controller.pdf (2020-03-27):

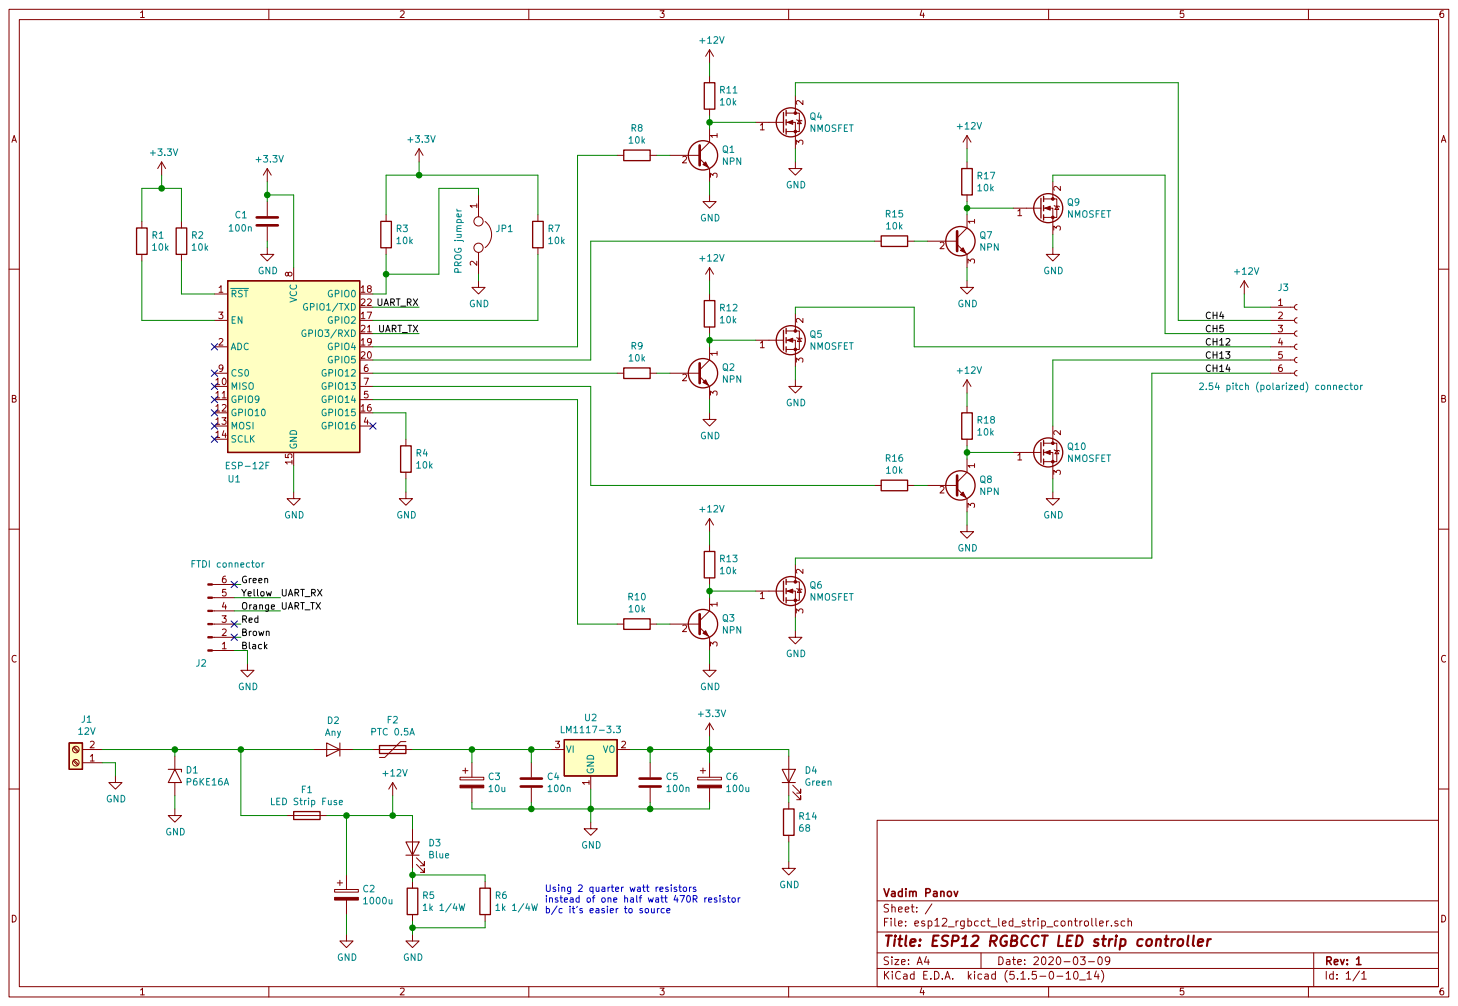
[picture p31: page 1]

File: esp12_rgbcct_led_strip_controller.sch Sheet: / Vadim Panov

instead of one half watt 470R resistor b/c its easier to source

Id: 1/1 Title: ESP12 RGBCCT LED strip controller

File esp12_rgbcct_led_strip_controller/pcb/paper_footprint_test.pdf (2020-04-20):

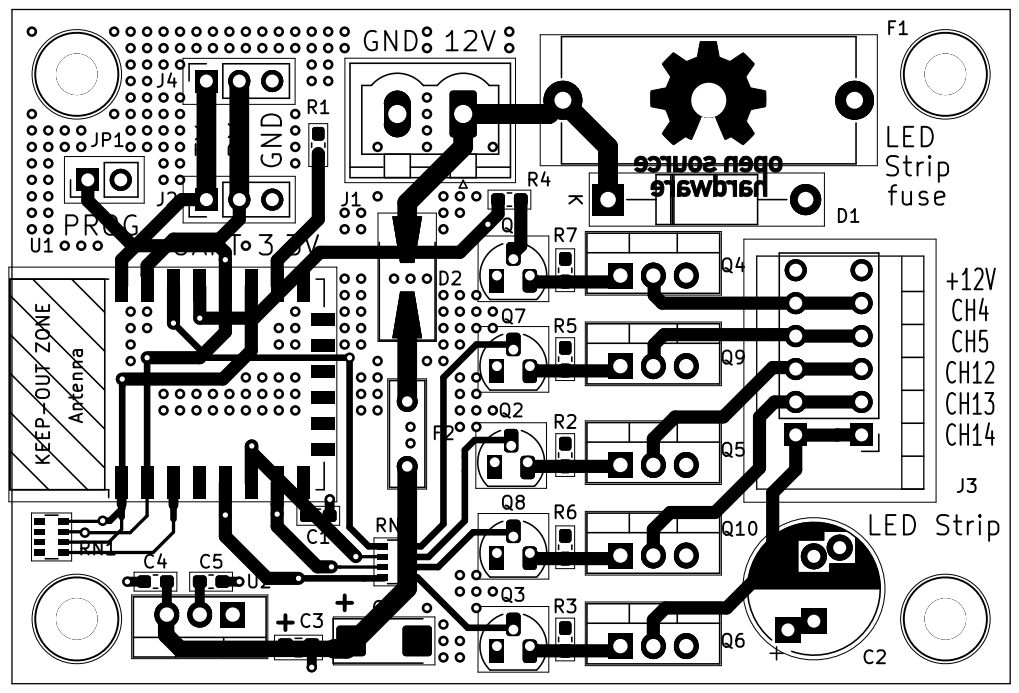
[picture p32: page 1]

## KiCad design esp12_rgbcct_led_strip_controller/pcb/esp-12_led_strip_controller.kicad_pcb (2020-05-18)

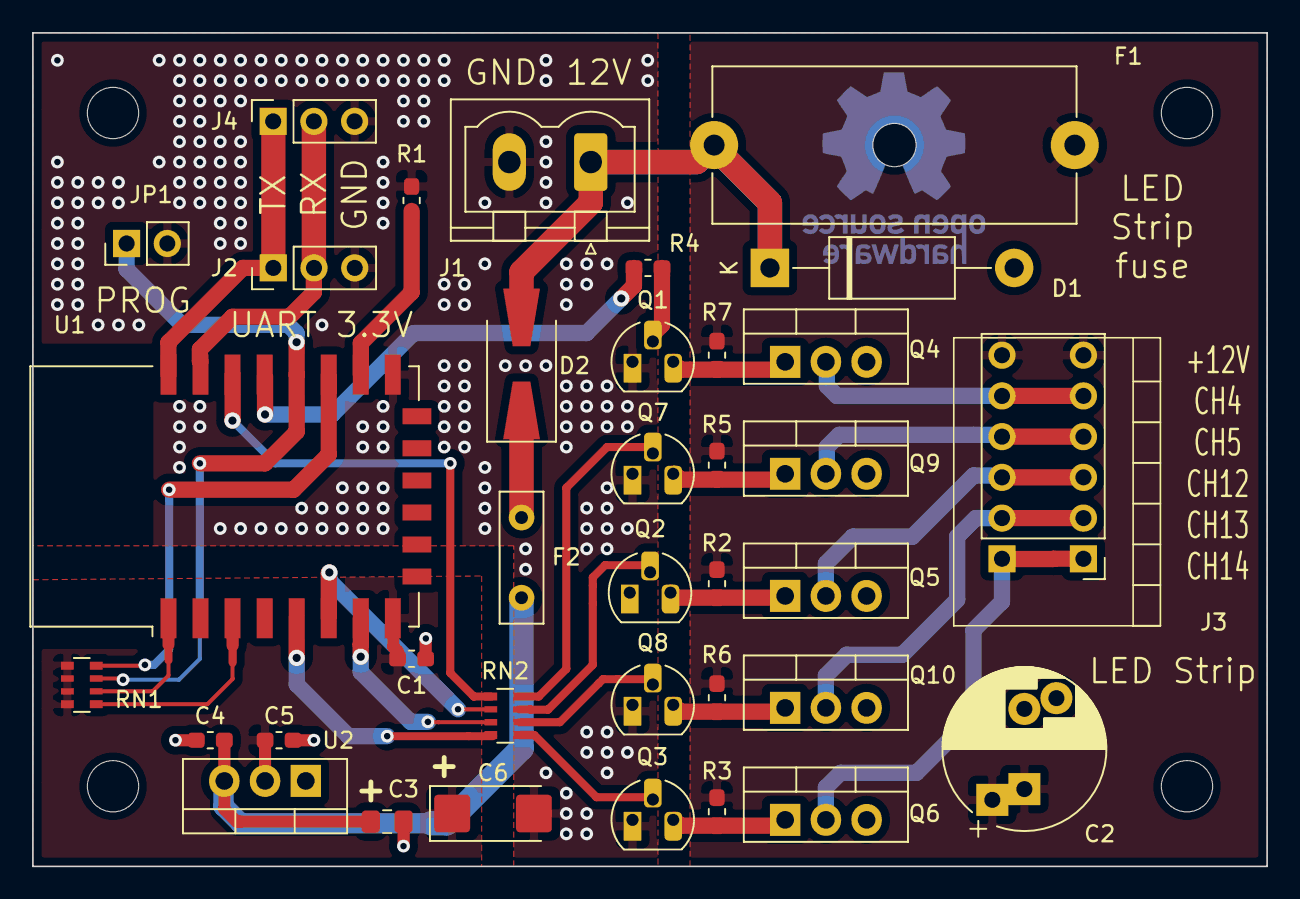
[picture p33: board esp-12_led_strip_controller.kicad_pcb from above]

Board: 2 copper layers, 77.0 x 52.0 mm, 36 parts (0 on the bottom side), 33 nets.

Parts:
C1, C4, C5: 100n; C_0603_1608Metric_Pad1.05x0.95mm_HandSolder
C2: 1000u; CP_Radial_D10.0mm_P5.00mm_P7.50mm
C3: 10u; C_0805_2012Metric_Pad1.15x1.40mm_HandSolder
C6: 100u; CP_EIA-6032-28_Kemet-C_Pad2.25x2.35mm_HandSolder
D1: P6KE16A; D_DO-15_P15.24mm_Horizontal
D2: Any; D_SMA-SMB_Universal_Handsoldering
F1: LED Strip Fuse; Fuseholder_Cylinder-5x20mm_Schurter_0031_8201_Horizontal_Op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
F2: PTC 0.5A; C_Disc_D8.0mm_W2.5mm_P5.00mm
J1: 12V; PhoenixContact_MSTBVA_2,5_2-G-5,08_1x02_P5.08mm_Vertical
J2: UART_M; PinHeader_1x03_P2.54mm_Vertical
J3: LED Strip; KF141V-6P_P2.54mm
J4: UART_F; PinSocket_1x03_P2.54mm_Vertical
JP1: PROG jumper; PinHeader_1x02_P2.54mm_Vertical
Q1, Q2, Q3, Q7, Q8: NPN_EBC; TO-92_HandSolder
Q4, Q5, Q6, Q9, Q10: NMOSFET_GDS; TO-220-3_Vertical
R1, R2, R3, R4, R5, R6, R7: 10k; R_0603_1608Metric_Pad1.05x0.95mm_HandSolder
RN1, RN2: 10k; R_Array_Convex_4x0603
U1: ESP-12F; ESP-12E
U2: LM1117-3.3; TO-220-3_Vertical

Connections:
+3V3: C1.1, C5.1, C6.1, RN1.5, RN1.6, RN1.7, RN1.8, U1.8, U2.2
+12V: C2.1, F1.1, J3.6, R2.1, R3.1, R5.1, R6.1, R7.1
/CH4: J3.5, Q4.2
/CH5: J3.4, Q9.2
/CH12: J3.3, Q5.2
/CH13: J3.2, Q10.2
/CH14: J3.1, Q6.2
/UART_RX: J2.2, J4.2, U1.21
/UART_TX: J2.1, J4.1, U1.22
GND: C1.2, C2.2, C3.2, C4.2, C5.2, C6.2, D1.2, J1.2, J2.3, J4.3, JP1.2, Q1.1, Q2.1, Q3.1, Q4.3, Q5.3, Q6.3, Q7.1, Q8.1, Q9.3, Q10.3, R1.2, U1.15, U2.1
unnamed: C3.1, C4.1, F2.1, U2.3
unnamed: D1.1, D2.2, F1.2, J1.1
unnamed: D2.1, F2.2
unnamed: JP1.1, RN1.3, U1.18
unnamed: Q1.2, R4.1
unnamed: Q1.3, Q4.1, R7.2
unnamed: Q2.2, RN2.7
unnamed: Q2.3, Q5.1, R2.2
unnamed: Q3.2, RN2.5
unnamed: Q3.3, Q6.1, R3.2
unnamed: Q7.2, RN2.8
unnamed: Q7.3, Q9.1, R5.2
unnamed: Q8.2, RN2.6
unnamed: Q8.3, Q10.1, R6.2
unnamed: R1.1, U1.16
unnamed: R4.2, U1.19
unnamed: RN1.1, U1.3
unnamed: RN1.2, U1.1
unnamed: RN1.4, U1.17
unnamed: RN2.1, U1.20
unnamed: RN2.2, U1.6
unnamed: RN2.3, U1.7
unnamed: RN2.4, U1.5

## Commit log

2020-03-27 Neopixel and RGBCCT controllers
    ESP01 neopixel controller + ESP12 RGBCCT LED strip controller, breadboard only for now
    [esp01_neopixel_controller.sch, esp12_rgbcct_led_strip_controller.sch]
2020-03-29 base led strip controller for PCB
    [esp-12_led_strip_controller.sch]
2020-04-20 esp-12 led strip controller PCB
    [Ultimate_Box.scad, back.stl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]
2020-05-08 waterproof enclosure for ESP12 board
    more renders
    [SP16-2P, female, back nut type, with cap.stp, SP16-6P, female, back nut type, with cap.stp, enclosure_bottom.stl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]
2020-05-11 remove extra drill holes
    [enclosure_top.stl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]
2020-05-11 update readme.md
    include BOM
2020-05-12 update bom
    commit csv bom
    [bom.csv]
2020-05-18 increase via size
    [1_bom.csv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]
2020-05-27 higher openscad box
    [back.stl, front.stl, full_assembly.FCStd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]
2020-06-02 post-print update for RGBCCT c. box
    [Ultimate_Box.scad, back.stl, front.stl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]
2020-06-03 waterproof enclosure
    bigger SP16 holes
    switch to countersunk bolts
    [enclosure_bottom.stl, enclosure_top.stl]
2021-03-28 minor fixes
    [1_bom.csv]
